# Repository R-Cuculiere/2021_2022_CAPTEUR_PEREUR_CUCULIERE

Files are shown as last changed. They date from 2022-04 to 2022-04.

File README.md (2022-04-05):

# 2022_CAPTEUR_Pereur_Cuculière
--------------------------------
## Sommaire

--------------------------------
## Etapes de conception (Générales)

- Design et simulations du circuit d'amplification sous LtSpice
- Implémentation du circuit sous KiCAD et design du PCB
- 

--------------------------------
## Design et simulations du circuit analogique - SHIELD

--------------------------------
## Conception du SHIELD sous KiCAD

Nous avons commencé par le l'implémentation de l'amplificateur transimpédance dans le schéma électrique global du SHIELD visible ci-dessous : 


Nous avons ensuite procédé au routage du PCB : 

Routage
2022-SHIELD-PCB

Visualisation 3D
2022-SHIELD-PCB_3D

--------------------------------
## Développement du programme Arduino

--------------------------------
## Banc de tests

--------------------------------
## Création de la datasheet

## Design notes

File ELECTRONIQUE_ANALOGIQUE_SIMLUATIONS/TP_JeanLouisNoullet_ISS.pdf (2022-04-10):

# ISS - UF Smart Devices : partie analogique

English version here

## 1. Mesure d'une résistance

Méthodes classiques :

- imposer I, mesurer V
- imposer V, mesurer I
- alimenter, mesurer V et I
- alimenter, mesurer R par identification (pont)

Cas du capteur de gaz à nano-particules :

- très faible courant : de l'ordre de 100 nA
- effet tunnel : forte non-linéarité de I(V)

Alors quelle technique adopter pour extraire l'information utile du capteur ?

## 2. Mesure de faible courant avec un micro-contrôleur

Parametres des microcontrôleurs courants en 2016
(AVR/Arduino, STM32, PIC Microchip, etc...) :
- résolution 10 à 12 bits (1024 à 4096 points)
- pleine échelle (VRef) de 1.1 V à 5.0 V
- impédance de source max 1 kOhm à 10 kOhm
- fréquence d'échantillonnage max 15 kHz à 2.4 MHz
La mesure directe d'un courant de 100 nA ne parait pas praticable.
N.B. la valeur max d'impédance de source est spécifiée en fonction de l' échantillonneur à capacité commutée présent à l'entrée de l'ADC.

Solution "classique" :

L'amplificateur transimpédance.

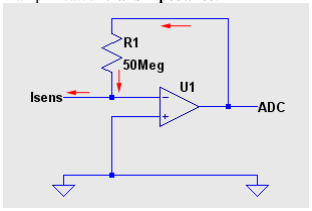
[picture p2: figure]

Problèmes posés par cette solution :

- nécessite une très grande valeur pour R1
- nécessite une tension négative pour alimenter le capteur

Solution "classique" améliorée :

L'amplificateur transimpédance suivi d'un étage amplificateur inverseur.

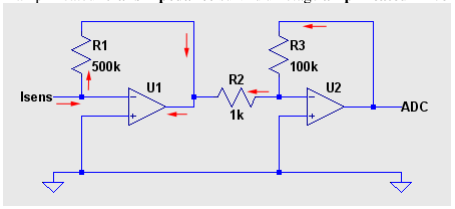
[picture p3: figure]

- grâce au gain du second étage, la résistance R1 n'a pas besoin d'être grande
- grâce à l'inversion, l'alimentation du capteur peut être positive
- cependant il faut une alimentation bipolaire pour les amplis

Solution minimaliste :

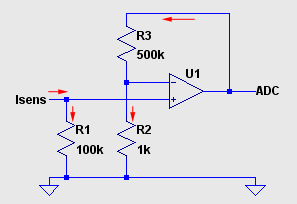
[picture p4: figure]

- conversion I-->U dans la résistance d'épreuve R1 (shunt)
- amplification à fort gain par montage non-inverseur
- la chute de tension sur R1 perturbe (un peu) la tension appliquée au capteur
- peut fonctionner avec seulement une alimentation positive

Remarques :
Gain de l’étage de l’AOP : (R2+R3)/R2=(1k+500k)/1k=501
Tension aux bornes de R1 : le courant Isens est d’environ 100nA
- V = 100kOhm*100nA=10⁻²V=10mV
Tension sur l’ADC : Gain*Tension aux bornes de R1 => 501*10x10⁻³~5V

Contraintes sur le choix de l'ampli :

- faible courant d'entrée

- ultra-faible offset de tension
- supporte mode commun à la tension d'alim négative ("low rail")

Remarques :
(1) offset voltage = erreur constante aux entrées de l’amplificateur différentiel dû à un état non compensé sur l’étage d’entrée de l’amplificateur. On veut que cet offset soit négligeable devant la tension mesurée sur R1 qui sera de 10mV.
(2) Le courant d’entrée doit être très petit devant Isens pour avoir le Isens traverse la R1 et pas l’entrée
(3) Mode commun : tension commune aux deux entrées, un bon amplifieur sera insensible à ce mode commun. Si le Isens =0A ,on veut 0V sur l’ADC. LTC1050C => 5µV offset voltage, et maximum offset voltage drift : 0.05µV/°C. Bien comparé aux 10mV aux bornes de R1.

L'ampli LTC1050C est disponible, satisfait-il ces contraintes ?

## 3. Filtrage passe-bas

Une bande passante de l'ordre de 1 Hz est largement suffisante pour extraire toute l'information utile du capteur, dont l'inertie est importante.

Un montage aussi sensible étant très vulnérable au bruit à 50Hz (+ harmoniques) résultant du couplage capacitif avec le réseau 230V, un filtrage passe-bas est indispensable.
D'autres sources de bruit à filtrer sont les horloges de circuits digitaux (microcontrôleur, afficheurs, etc...) et les transceivers RF (bluetooth, etc...).

Ce filtrage peut être effectué en partie du coté digital, par programme, sur le microcontrôleur.
Cependant un filtrage analogique est indispensable, en effet un excès de bruit à l'entrée de l'ADC pourrait amener celui-ci à saturation.
De plus un filtrage anti-repliement (anti-aliasing) est indispensable en raison de l'échantillonnage effectué par l'ADC.
Pour faciliter ce filtrage on a intérêt à faire fonctionner l'ADC à la plus GRANDE fréquence utilisable SANS PERTE DE QUALITE (dans le cas de l'Arduino Uno, 200kHz/13 = 15.4 kHz, avec un choix de prescaler à 128 ! (cf wiring.c).

Le filtrage peut s'implanter dans 3 régions de la chaîne de traitement analogique :

- filtre passif à l'entrée : permet d'éviter que les bruits HF causent de la distorsion dans les étages d'entrée
- filtre actif basé sur les amplificateurs opérationnels : maximum d'efficacité
- filtre passif en fin de chaine, coté ADC, pour retirer le bruit introduit en cours de traitement (bruit d'alimentation, bruit d'horloge des amplificateurs à découpage)

Schéma Suggéré

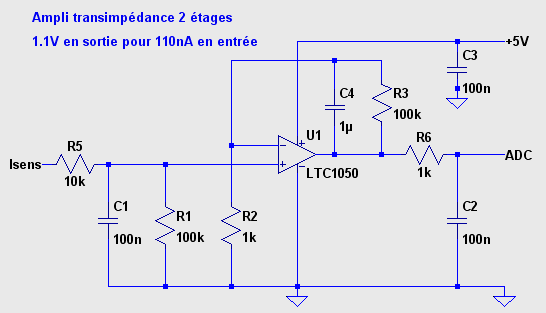
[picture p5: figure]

- R5 en entrée protège l'ampli opérationnel contre les décharges électrostatiques, en forme avec C1 un filtre pour les bruits en tension
- C1 avec R1 forme un filtre pour le bruit en courant
- R2 sera interchangeable, pour permettre une adaptation du calibre
- C4 avec R3 forme un filtre actif
- C2 avec R6 forme le filtre de sortie
- C3 filtre le bruit d'alimentation

## 4. Questions

A l’aide du simulateur LTSpice IV :

1. Vérifier la fonctionnalité dans les conditions nominales 2. L'incidence de l'offset de l'amplificateur LTC1050C est-elle acceptable ? 3. L'incidence du courant d'entrée de l'amplificateur est-elle acceptable ? 4. Quelle est la fréquence de coupure de chaque étage de filtre passe-bas ? 5. Quelle est l'atténuation globale d'un bruit en courant de 50 Hz ?

6. Quelle est l'atténuation globale d'un bruit en courant à la fréquence limite de repliement (dans le cas de l'ADC Arduino Uno) ?

### 7. Préparez une simulation de démonstration avec :

- un capteur alimenté en 5V dont la conductance varie de 10 nS à 20 nS en 0.5s (l’utilisation d’un filtre passe-bas pourrait être utile !).

### 1. Mettre en évidence l’intérêt du filtrage 50Hz choisi en visualisant

l’impact d’un bruit de 1% sur la source d’alimentation du capteur

### 2. Quand est-ce que ce bruit devient gênant ?

- Pour s’approcher des conditions réelles de mesures réalisées à l’AIME, vous modifierez le montage précédent pour mettre une alimentation de 20V sur le capteur (à la place de la 5V) et conserverez l’alimentation de 5V sur l’AOP.

### 1. Peut-on réaliser ce montage sur un Arduino Uno ?

- une source de bruit de 230V RMS à 50Hz, couplée au noeud d'entrée par une capacité de 1 pF
- Serait-il intéressant d’ajouter un montage dérivateur pour mesurer directement le coefficient cinétique de la réaction chimique du capteur avec un gaz ?

### 1. Si oui, proposez un montage !

N.B. pour simuler une conductance variable, utiliser l'élément Arbitrary current source (symbole BI) de LTSpice contrôlé par une source de tension indépendante représentant la variation de concentration du gaz atteignant le capteur

8. Donner une expression analytique de la résistance du capteur en fonction des éléments du circuit transimpédance.

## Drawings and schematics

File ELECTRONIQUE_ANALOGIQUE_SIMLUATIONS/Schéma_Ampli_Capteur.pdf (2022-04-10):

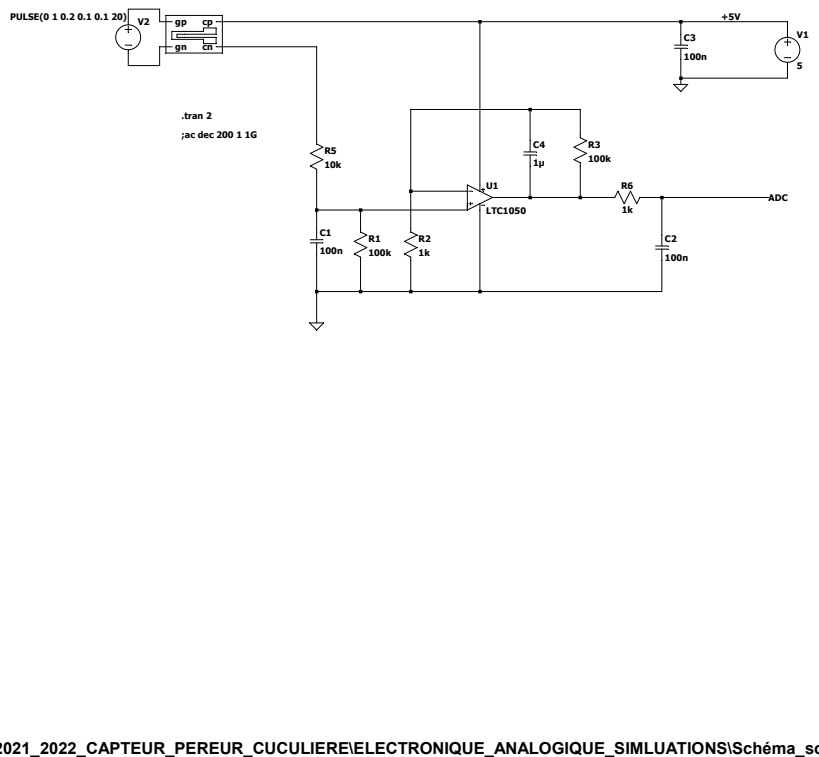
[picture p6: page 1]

--- C:\Users\Rémi\Documents\GitHub\2021_2022_CAPTEUR_PEREUR_CUCULIERE\ELECTRONIQUE_ANALOGIQUE_SIMLUATIONS\Schéma_solution_Ampli_Transimpédance.asc ---

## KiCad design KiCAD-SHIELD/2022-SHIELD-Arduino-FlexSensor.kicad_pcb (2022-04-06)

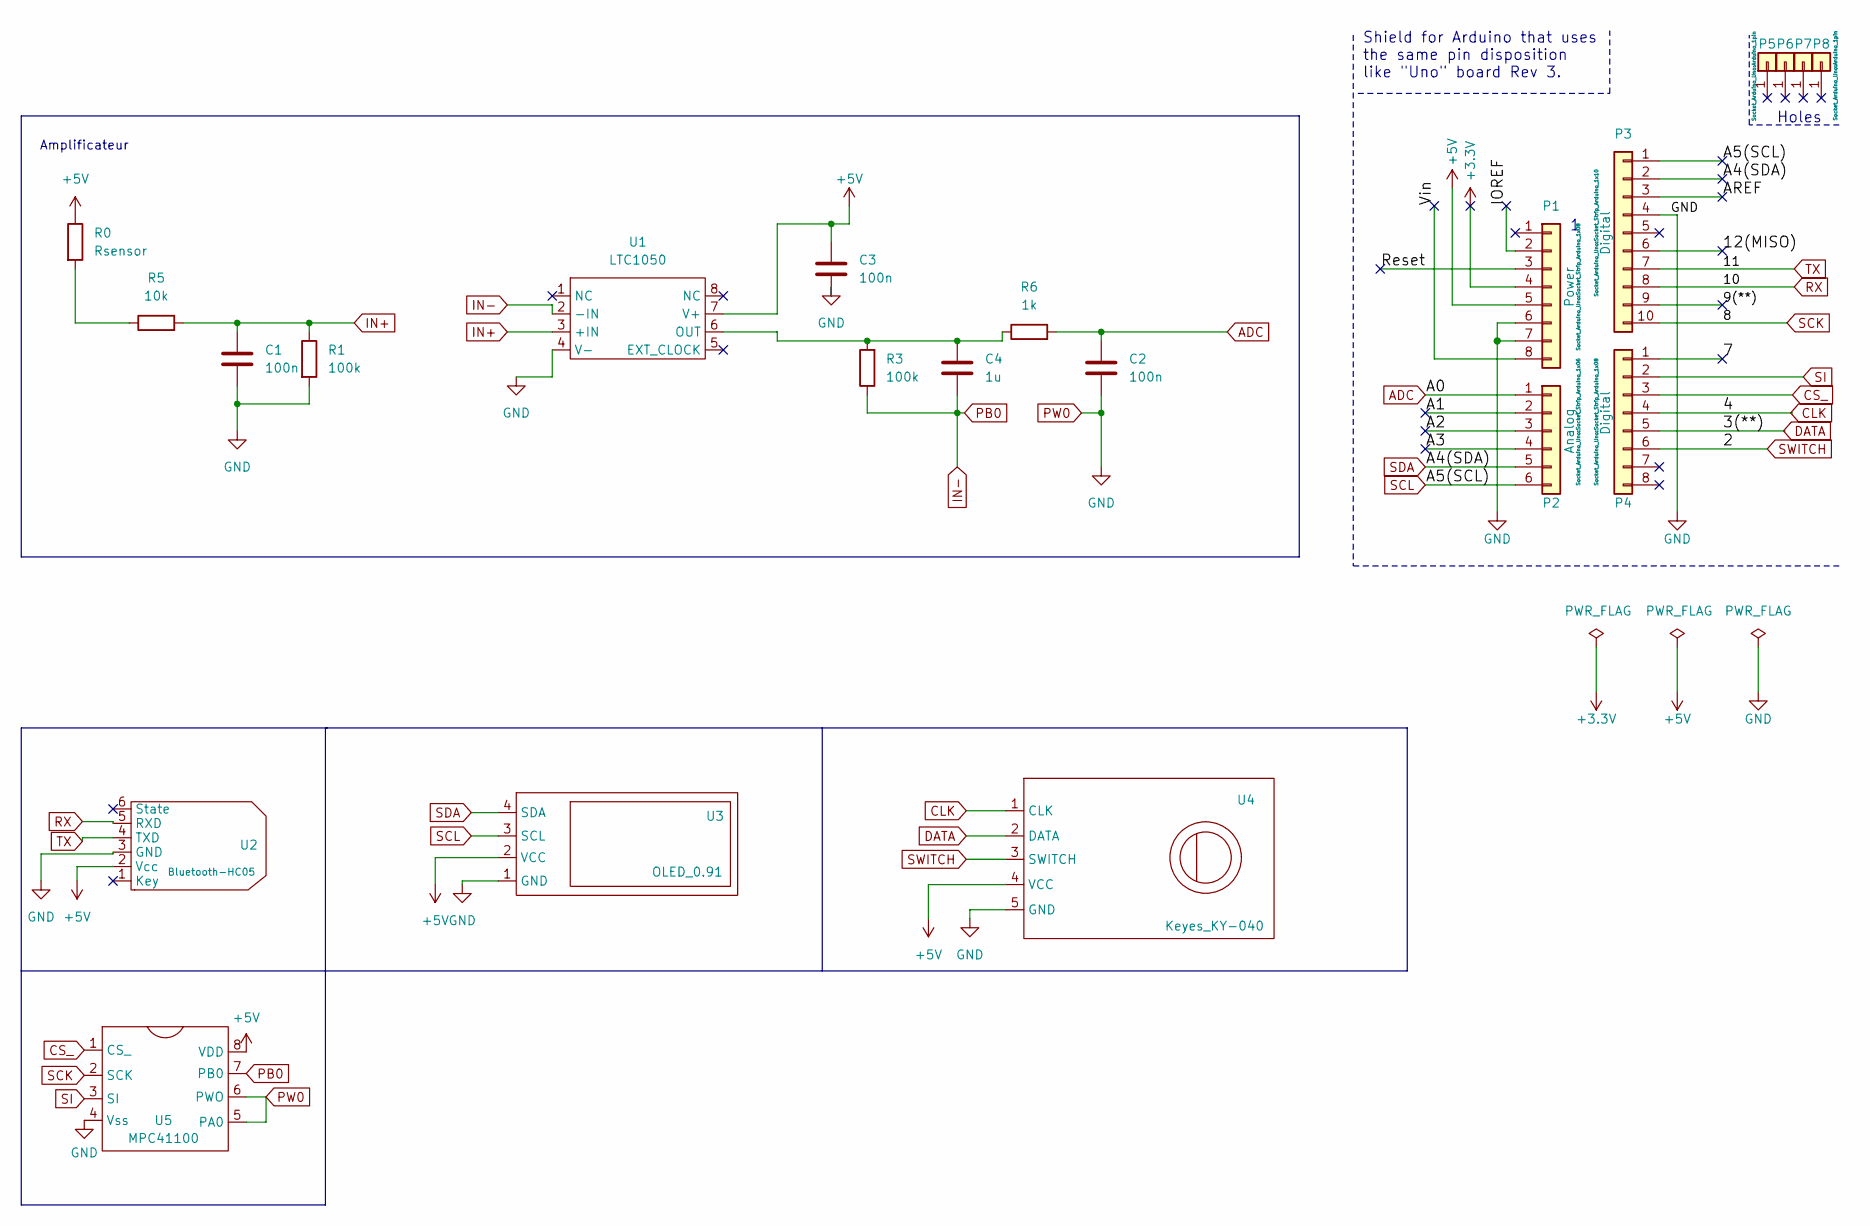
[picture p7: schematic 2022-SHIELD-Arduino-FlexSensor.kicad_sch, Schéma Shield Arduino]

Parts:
C1, C3: 100n; C_Disc_D4.3mm_W1.9mm_P5.00mm
C2: 100n; C_Disc_D7.5mm_W5.0mm_P7.50mm
C4: 1u; C_Rect_L7.0mm_W4.5mm_P5.00mm
P1: Power; Socket_Strip_Arduino_1x08
P2: Analog; Socket_Strip_Arduino_1x06
P3: Digital; Socket_Strip_Arduino_1x10
P4: Digital; Socket_Strip_Arduino_1x08
P5, P6, P7, P8: CONN_01X01; Arduino_1pin
R0: Rsensor
R1, R3: 100k; R_Axial_DIN0207_L6.3mm_D2.5mm_P7.62mm_Horizontal
R5: 10k; R_Axial_DIN0207_L6.3mm_D2.5mm_P7.62mm_Horizontal
R6: 1k; R_Axial_DIN0204_L3.6mm_D1.6mm_P7.62mm_Horizontal
U1: LTC1050
U2: Bluetooth-HC05; HC-05
U3: OLED_0.91; SIP-4
U4: Keyes_KY-040; KY-040
U5: MPC41100; MPC41100_FP

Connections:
+3V3: P1.4
+5V: C3.1, P1.5, R0.1, U1.7 (V+), U2.2 (Vcc), U3.2 (VCC), U4.4 (VCC), U5.8 (VDD)
/7: P4.1
/9(**): P3.9
/12(MISO): P3.6
/A1: P2.2
/A2: P2.3
/A3: P2.4
/AREF: P3.3
/IOREF: P1.2
/Reset: P1.3
/Vin: P1.8
ADC: C2.1, P2.1, R6.2
CLK: P4.4, U4.1 (CLK)
CS_: P4.3, U5.1 (CS_)
DATA: P4.5, U4.2 (DATA)
IN+: C1.1, R1.1, R5.2, U1.3 (+IN)
IN-: C4.2, R3.1, U1.2 (-IN), U5.7 (PB0)
unnamed: C4.1, R3.2, R6.1, U1.6 (OUT)
unnamed: R0.2, R5.1
RX: P3.8, U2.5 (RXD)
SCK: P3.10, U5.2 (SCK)
SCL: P2.6, P3.1, U3.3 (SCL)
SDA: P2.5, P3.2, U3.4 (SDA)
SI: P4.2, U5.3 (SI)
SWITCH: P4.6, U4.3 (SWITCH)
TX: P3.7, U2.4 (TXD)

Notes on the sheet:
Holes
Shield for Arduino that uses the same pin disposition like "Uno" board Rev 3.
Amplificateur

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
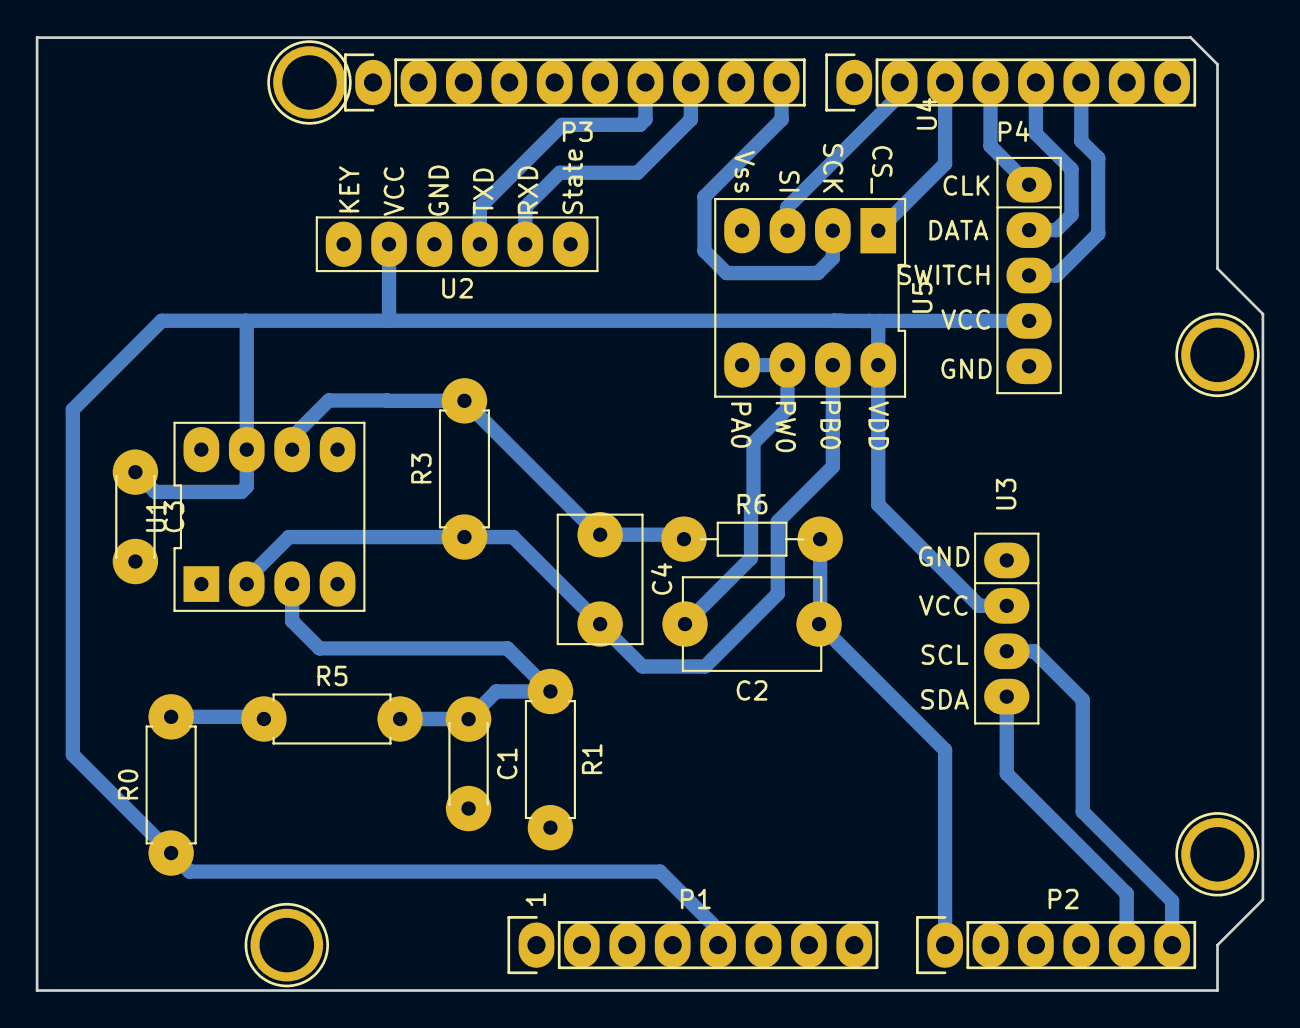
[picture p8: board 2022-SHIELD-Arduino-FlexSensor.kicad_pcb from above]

Board: 2 copper layers, 68.6 x 53.3 mm, 22 parts (0 on the bottom side), 18 nets.

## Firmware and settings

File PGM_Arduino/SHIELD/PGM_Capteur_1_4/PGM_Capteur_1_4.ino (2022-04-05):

#include <Wire.h>
#include <Adafruit_SSD1306.h>
#include <Adafruit_GFX.h>
#include <SoftwareSerial.h>
#include <SPI.h>

// Définintions OLED

#define nombreDePixelsEnLargeur 128         // Taille de l'écran OLED, en pixel, au niveau de sa largeur
#define nombreDePixelsEnHauteur 64          // Taille de l'écran OLED, en pixel, au niveau de sa hauteur
#define brocheResetOLED         -1          // Reset de l'OLED partagé avec l'Arduino (d'où la valeur à -1, et non un numéro de pin)
#define adresseI2CecranOLED     0x3C        // Adresse de "mon" écran OLED sur le bus i2c (généralement égal à 0x3C ou 0x3D)

Adafruit_SSD1306 OLED(nombreDePixelsEnLargeur, nombreDePixelsEnHauteur, &Wire, brocheResetOLED);

// Définitions encodeur rotatoire

#define pinClk  3
#define pinData  4
#define pinSw 2

volatile unsigned int encoderPos = 1;
volatile unsigned int encoderPos1 = 5; //position par défaut de la sélection des sous-menu

byte clk;
byte dir = 0;
bool runState = false;

bool swState  = HIGH;
bool swLast  = HIGH;
bool menuType = HIGH;


// Définitions Module bluetooth

#define rxPin 5 //Broche 5 en tant que RX, � raccorder sur TX du HC-05
#define txPin 6 //Broche 6 en tant que RX, � raccorder sur TX du HC-05
#define baudrate 9600
SoftwareSerial mySerial(rxPin ,txPin); //D�finition du software serial

// Déclarations variables debouncing

int lastDebounceTime = 0;
int debounceDelay = 150;


float Vadc = 0.0;
float R3 = 100000.0;
float R1 = 100000.0;
float R2 ;
float R5 = 10000.0;
float Vcc = 5.0;
float Rcapteur = 0.0;

// Déclarations Calibration

float flatR = 0.0 ;
float upR = 0.0 ;
float downR = 0.0 ;
bool menuAactive = LOW ;

// SPI def

const byte csPin           = 10;      // MCP42100 chip select pin
const int  maxPositions    = 256;     // wiper can move from 0 to 255 = 256 positions
const long rAB             = 46200;   // 100k pot resistance between terminals A and B, 
                                      // mais pour ajuster au multimètre, je mets 92500
const byte rWiper          = 125;     // 125 ohms pot wiper resistance
const byte pot0            = 0x11;    // pot0 addr // B 0001 0001
const byte pot0Shutdown    = 0x21;    // pot0 shutdown // B 0010 0001

void setPotWiper(int addr, int pos) {
  pos = constrain(pos, 0, 255);            // limit wiper setting to range of 0 to 255
  digitalWrite(csPin, LOW);                // select chip
  SPI.transfer(addr);                      // configure target pot with wiper position
  SPI.transfer(pos);
  digitalWrite(csPin, HIGH);               // de-select chip

  // print pot resistance between wiper and B terminal
  long resistanceWB = ((rAB * pos) / maxPositions ) + rWiper;
//  Serial.print("Wiper position: ");
//  Serial.print(pos);
//  Serial.print(" Resistance wiper to B terminal: ");
//  Serial.print(resistanceWB);
//  Serial.println(" ohms");
  R2 = resistanceWB;
}


/****************************SETUP********************************/

void setup() {
  
  // Initialisation de l'écran OLED
  if(!OLED.begin(SSD1306_SWITCHCAPVCC, adresseI2CecranOLED))
    while(1);                               // Arrêt du programme (boucle infinie) si échec d'initialisation
  boolean bCouleurInverse = false;
  OLED.clearDisplay();
  OLED.setTextColor(WHITE);

  // SETUP Encodeur

  pinMode(pinClk,INPUT);
  pinMode(pinData,INPUT);
  pinMode(pinSw,INPUT_PULLUP);

  attachInterrupt(digitalPinToInterrupt(pinClk), doEncoder, CHANGE);  // encoder pin on interrupt 1 - pin 3
  attachInterrupt(digitalPinToInterrupt(pinSw), doSwitch, CHANGE);

  // setup module bluetooth

  pinMode(rxPin,INPUT);
  pinMode(txPin,OUTPUT);
    
  mySerial.begin(baudrate);
  
  // ouverture port serie
  Serial.begin(38400);

  // Initialisation SPI

  digitalWrite(csPin, HIGH);        // chip select default to de-selected
  pinMode(csPin, OUTPUT);           // configure chip select as output
  SPI.begin();
  
}


/****************************LOOP********************************/

void loop() {
  
  // Mesure et calcul de la résistance
  
  setPotWiper(pot0, 3);
  Vadc = (Vcc*analogRead(A0))/1023.0;
  Rcapteur = (1+R3/R2)*R1*(Vcc/Vadc)-R1-R5;

  //OLED

  calibration();
  menuOLED();
  OLED.clearDisplay();

  //test module bluetooth
  mySerial.print(Rcapteur);

  //TESTS



  delay(50);
}


/*******calibration*******/

void calibration(){

  if(menuType == HIGH && encoderPos1 == 3){
    OLED.setTextSize(1);
    //OLED.setTextColor(WHITE);
    OLED.setCursor(10, 0);
    OLED.println("Mettez le capteur vers le bas");

    OLED.setCursor(10, 20);
    OLED.println(Rcapteur/1000000.0);
    
    OLED.setCursor(10, 40);
    OLED.println("Cliquez pour continuer");

    downR = Rcapteur/1000000.0;

    OLED.display();
    OLED.clearDisplay();
  }
  if(menuType == HIGH && encoderPos1 == 2){
    OLED.setTextSize(1);
    //OLED.setTextColor(WHITE);
    OLED.setCursor(10, 0);
    OLED.println("Mettez le capteur vers le haut");

    OLED.setCursor(10, 20);
    OLED.println(Rcapteur/1000000.0);
    
    OLED.setCursor(10, 40);
    OLED.println("Cliquez pour continuer");

    upR = Rcapteur/1000000.0;

    OLED.display();
    OLED.clearDisplay();
  }
  
}


/***************MenuDef***************/

/*******menuOLED*******/

void menuOLED(){

  if(menuType==HIGH && encoderPos1==5){
    staticMenu();
    menuAactive = LOW;
    }
  if(menuType==LOW && encoderPos==1){
    menuA();
    menuAactive = HIGH;
    }
  if(menuType==LOW && encoderPos==2){menuB();}
  if(menuType==LOW && encoderPos==3){menuC();}
  
}

/*******staticMenu*******/
// Menu de démarrage

void staticMenu() {
  OLED.setTextSize(1);
  //OLED.setTextColor(WHITE);

  //---------------------------------
  OLED.setTextSize(1);
  OLED.setCursor(10, 0);
  OLED.println("CALIBRE");

  OLED.setCursor(10, 10);
  OLED.println("RESISTANCE");

  OLED.setCursor(10, 20);
  OLED.println("CREDIT");

  // Curseur de selection
  OLED.setCursor(2, (encoderPos * 10)- 10);
  OLED.println(">");

  OLED.display();

  OLED.clearDisplay();
}

/*******menuA*******/
// Menu de calibration (à programmer)

void menuA(){
  
  
  OLED.setTextSize(1);
  OLED.setCursor(10, 0);
  OLED.println("CALIBRE");

  OLED.setCursor(10, 10);
  OLED.println("MAX");
  OLED.setCursor(60, 10);
  OLED.println(upR);
  

  OLED.setCursor(10, 20);
  OLED.println("MIN");
  OLED.setCursor(60, 20);
  OLED.println(downR);


  OLED.setCursor(10, 40);
  OLED.println("Click to go back");

  // Curseur de selection
  OLED.setCursor(2, (encoderPos1 * 10)- 10);
  OLED.println(">");

  OLED.display();

  delay(50);
  
  //OLED.clearDisplay();
}

/*******menuB*******/

void menuB(){
  OLED.setCursor(0,0);
  OLED.print("Resistance : ");
  OLED.print(Rcapteur/1000000.0);
  OLED.println(" MOhm");
  float angle = (((Rcapteur/1000000.0)-upR)/(downR-upR))*180;
  OLED.print("angle : ");
  OLED.println(angle);
  
  OLED.setCursor(10, 40);
  OLED.println("Click to go back");

  // Curseur de selection
  OLED.setCursor(2, (encoderPos1 * 10)- 10);
  OLED.println(">");
  
  OLED.display();
  OLED.clearDisplay();
}  

/*******menuC*******/
// Crédit du projet

void menuC(){
  
  OLED.setTextSize(1);
  //OLED.setTextColor(WHITE);
  OLED.setCursor(10, 0);
  OLED.println("CREDIT");

  OLED.setCursor(10, 10);
  OLED.println("CucLuc ou Luccuc");

  OLED.setCursor(10, 40);
  OLED.println("Click to go back");

  // Curseur de selection
  OLED.setCursor(2, (encoderPos1 * 10)- 10);
  OLED.println(">");

  OLED.display();
  
  OLED.clearDisplay();
}



/*******doSwitch*******/

void doSwitch(){

  swState = digitalRead(pinSw);
  if (swState == LOW && swLast == HIGH) {
    
    if(menuType == HIGH){
      menuType = LOW;
      }
    else if(menuType == LOW && encoderPos1 == 5 || menuType == LOW && menuAactive ){
      menuType = HIGH;
      }
  }
  swLast = swState;
  
  delay(100);
}


/*******doEncoder*******/

void doEncoder(){

  if ((millis() - lastDebounceTime) > debounceDelay)
  {
  
  if (digitalRead(pinClk)==digitalRead(pinData)){
    if(menuType==HIGH){
      if(encoderPos > 1){
       encoderPos --; 
      }
      else{
        encoderPos == 5;
      }
    }
    if(menuType==LOW){
      if(encoderPos1 > 1){
       encoderPos1 --; 
      }
      else{
      encoderPos1 == 5;
      }
    }
  }
  if (digitalRead(pinClk)!=digitalRead(pinData)){
    if(menuType==HIGH){
      if(encoderPos < 5){
       encoderPos ++; 
      }
      else{
        encoderPos == 1;
      }
    }
    if(menuType==LOW){
      if(encoderPos1 < 5){
       encoderPos1 ++; 
      }
      else{
      encoderPos1 == 1;
      }
    }
  }
  lastDebounceTime = millis();
  }
}

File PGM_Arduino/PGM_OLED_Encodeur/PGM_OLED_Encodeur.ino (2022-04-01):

#include <Wire.h>
#include <Adafruit_SSD1306.h>
#include <Adafruit_GFX.h>
#define OLED_ADDR   0x3C
Adafruit_SSD1306 display(-1);

//#if (SSD1306_LCDHEIGHT != 64)
//#error("Height incorrect, please fix Adafruit_SSD1306.h!");
//#endif
//
//#if (SSD1306_LCDHEIGHT != 64)
//#error("Height incorrect, please fix Adafruit_SSD1306.h!");
//#endif

#define pinClk  3
#define pinData  4
#define pinSw 2

volatile unsigned int encoderPos = 1;
volatile unsigned int encoderPos1 = 1;

byte clk;
byte menuCount = 0;
byte dir = 0;
bool runState = false;

bool swState  = HIGH;
bool swLast  = HIGH;
bool menuType = HIGH;

// Déclaration variables debouncing
int lastDebounceTime = 0;
int debounceDelay = 50;

int i = 0 ;

void setup() {
  Serial.begin(9600);
  display.begin(SSD1306_SWITCHCAPVCC, OLED_ADDR);
  display.display();
  display.clearDisplay();
  for(i;i<50;i++){
  display.drawLine(i*2, 1, 1000, 1000, WHITE);
  display.display();
  Serial.println(i);
  }
  display.clearDisplay();

  // Initialisation encodeur
  pinMode(pinClk,INPUT);
  pinMode(pinData,INPUT);
  pinMode(pinSw,INPUT_PULLUP);
 
  attachInterrupt(digitalPinToInterrupt(pinClk), doEncoder, CHANGE);  // encoder pin on interrupt 0 - pin 3
}

void loop() {
  
  
  
  Sw();
  menuOled();


  display.clearDisplay();
  
  delay(50);
}


// Test Switch

void Sw(){

  swState = digitalRead(pinSw);
  if (swState == LOW && swLast == HIGH) {
    Serial.print("Y");
    if(menuType == HIGH){
      menuType = LOW;
      Serial.println(LOW);
      }
    else{
      menuType = HIGH;
      Serial.println(HIGH);
      }
  }
  swLast = swState;
  delay(100);
}


// menuOled : Choix du menu

void menuOled(){

  if(menuType==HIGH){staticMenu();}
  if(menuType==LOW && encoderPos==1){menuA();}
  if(menuType==LOW && encoderPos==3){menuC();}
  
}

// staticMenu : menu de démarrage

void staticMenu() {
  display.setTextSize(1);
  display.setTextColor(WHITE);

  //---------------------------------
  display.setTextSize(1);
  display.setCursor(10, 0);
  display.println("CALIBRE");
  display.setCursor(60, 0);

  display.setCursor(10, 10);
  display.println("RESISTANCE");
  display.setCursor(60, 10);

  display.setCursor(10, 20);
  display.println("CREDIT");
  display.setCursor(60, 20);

  Serial.println(encoderPos);
  
  display.setCursor(2, (encoderPos * 10)- 10);
  display.println(">");

  display.display();

  display.clearDisplay();
}

// menuA : premier menu - Calibration

void menuA(){
  
  display.setTextSize(1);
  display.setTextColor(WHITE);
  display.setCursor(10, 0);
  display.println("CALIBRE");
  display.setCursor(60, 0);

  display.setCursor(10, 20);
  display.println("Click to go back");

  display.display();
  
  display.clearDisplay();
}

// menuC : Crédit du projet


void menuC(){
  
  display.setTextSize(1);
  display.setTextColor(WHITE);
  display.setCursor(10, 0);
  display.println("CREDIT");
  display.setCursor(60, 0);

  display.setCursor(10, 10);
  display.println("CucLuc ou Luccuc");

  display.setCursor(10, 20);
  display.println("Click to go back");

  display.display();
  
  display.clearDisplay();
}


// Interruption incrémentation de l'encodeur

void doEncoder(){

  if ((millis() - lastDebounceTime) > debounceDelay)
  {
  
  if (digitalRead(pinClk)==digitalRead(pinData)){
    if(menuType==HIGH){
      if(encoderPos > 1){
       encoderPos --; 
      }
      else{
        encoderPos == 3;
      }
    }
    if(menuType==LOW){
      if(encoderPos1 > 1){
       encoderPos1 --; 
      }
      else{
      encoderPos1 == 3;
      }
    }
  }
  if (digitalRead(pinClk)!=digitalRead(pinData)){
    if(menuType==HIGH){
      if(encoderPos < 3){
       encoderPos ++; 
      }
      else{
        encoderPos == 1;
      }
    }
    if(menuType==LOW){
      if(encoderPos1 < 3){
       encoderPos1 ++; 
      }
      else{
      encoderPos1 == 1;
      }
    }
  }
  lastDebounceTime = millis();
  }
}

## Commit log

2022-04-01 PGM Arduino
2022-04-06 Changement nom directory
    [2022-SHIELD-Arduino-FlexSensor.kicad_pcb, 2022-SHIELD-Arduino-FlexSensor.kicad_sch]
2022-04-08 Rajout partie électronique analogique
    Création et simulation de l'amplificateur relié au capteur sous LtSPICE
